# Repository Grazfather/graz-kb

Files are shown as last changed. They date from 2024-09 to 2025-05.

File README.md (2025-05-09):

# Graziano's keyboard

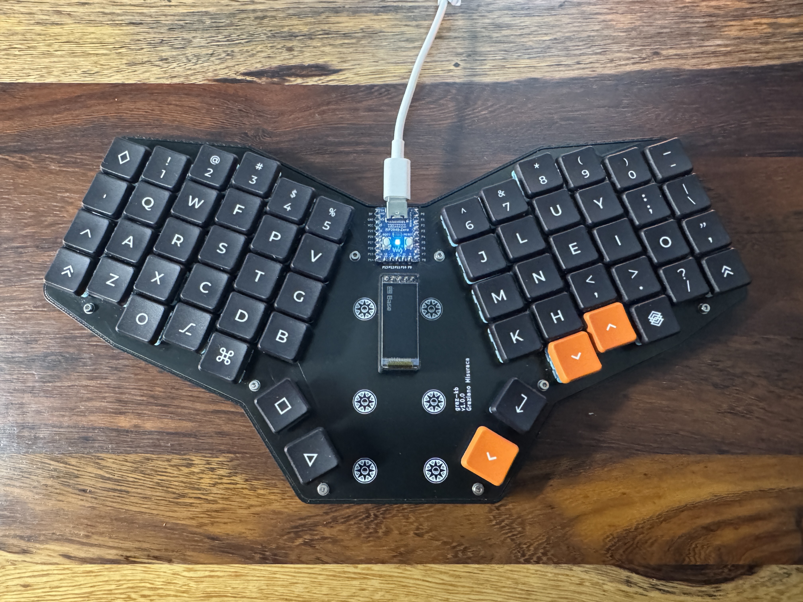
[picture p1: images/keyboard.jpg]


[ZMK configuration and keymap](https://github.com/Grazfather/zmk-config-grazkb)

* 58 key ergonomic wires keyboard.
* Full number row and alphabet (bare minimum for me)
* Low-profile choc switches
* 5 keys in the thumb cluster/row
* Designed using [Ergogen](https://github.com/ergogen/ergogen) and KiCad.
* ZMK Used for firmware.

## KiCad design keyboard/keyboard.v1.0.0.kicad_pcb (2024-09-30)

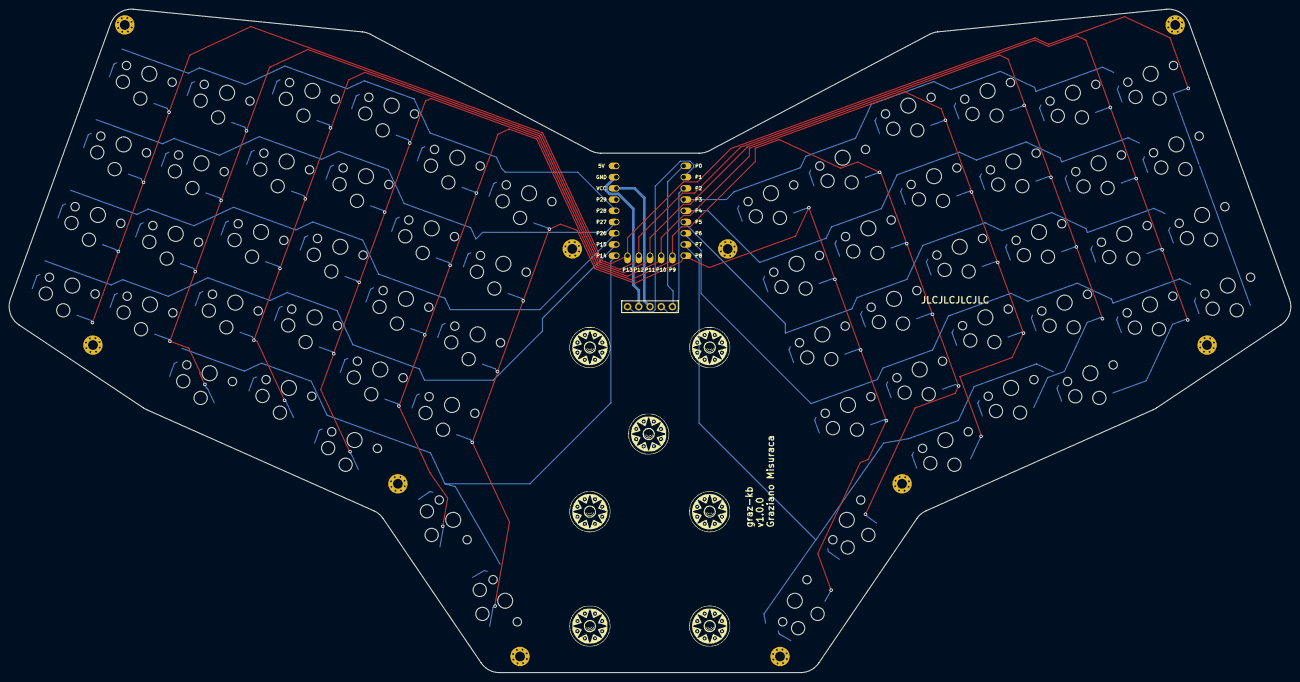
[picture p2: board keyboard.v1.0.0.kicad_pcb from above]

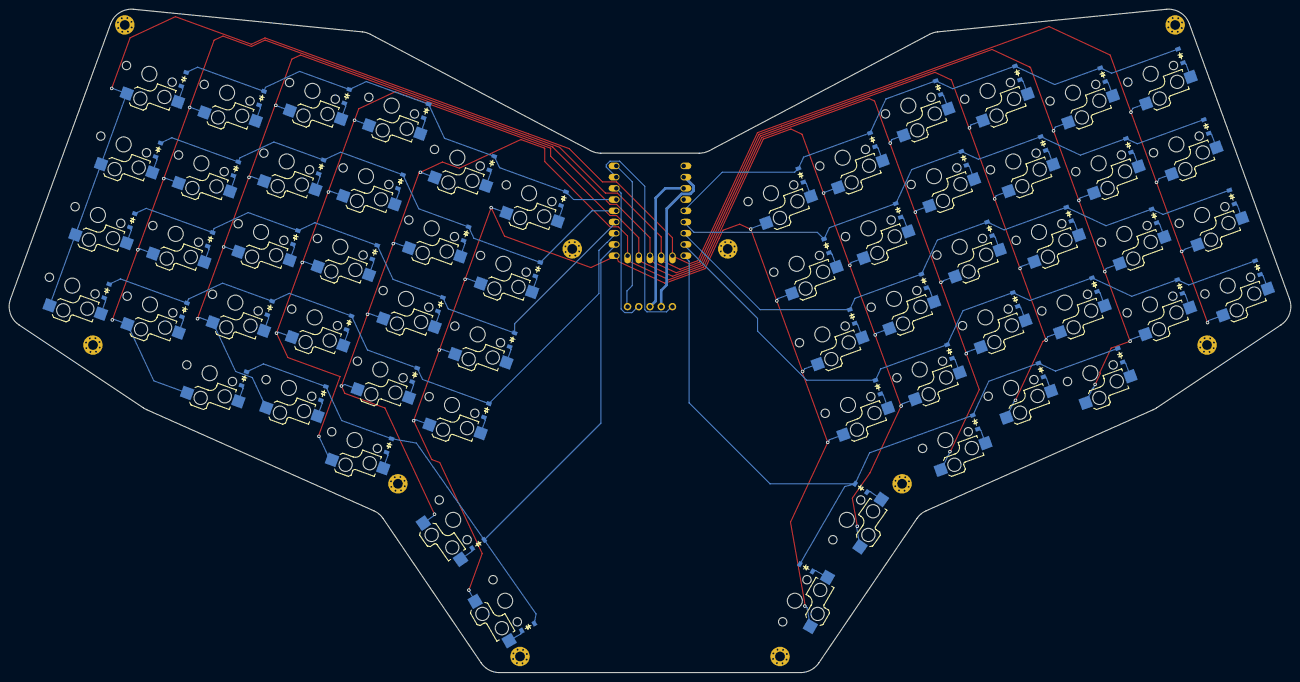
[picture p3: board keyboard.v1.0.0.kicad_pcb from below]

Board: 2 copper layers, 290.1 x 150.1 mm, 128 parts (116 on the bottom side), 79 nets.

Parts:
D1, D2, D3, D4, D5, D6, D7, D8, D9, D10, D11, D12, D13, D14, D15, D16, D17, D18, D19, D20, D21, D22, D23, D24, D25, D26, D27, D28, D29, D30, D31, D32, D33, D34, D35, D36, D37, D38, D39, D40, D41, D42, D43, D44, D45, D46, D47, D48, D49, D50, D51, D52, D53, D54, D55, D56, D57, D58: diode_tht_sod123
DISP1: nice_view
MCU1: Waveshare RP2040 Zero
S1, S2, S3, S4, S5, S6, S7, S8, S9, S10, S11, S12, S13, S14, S15, S16, S17, S18, S19, S20, S21, S22, S23, S24, S25, S26, S27, S28, S29, S30, S31, S32, S33, S34, S35, S36, S37, S38, S39, S40, S41, S42, S43, S44, S45, S46, S47, S48, S49, S50, S51, S52, S53, S54, S55, S56, S57, S58: switch_choc_v1_v2
_1, _2, _3, _3#2, _3#3, _4, _5, _6, _7, _8: MountingHole_2.2mm_M2_Pad_Via

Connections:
GND: DISP1.2, MCU1.22
OLED_MOSI: DISP1.5, MCU1.1
OLED_SCK: DISP1.4, MCU1.3
OLED_SS: DISP1.1, MCU1.2
VCC: DISP1.3, MCU1.21
col_index: MCU1.10, S20.1, S21.1, S22.1, S23.1, S28.1, S49.1, S50.1, S51.1, S52.1, S57.1
col_inner: MCU1.9, S24.1, S25.1, S26.1, S27.1, S29.1, S53.1, S54.1, S55.1, S56.1, S58.1
col_middle: MCU1.11, S15.1, S16.1, S17.1, S18.1, S19.1, S44.1, S45.1, S46.1, S47.1, S48.1
col_outer: MCU1.14, S1.1, S2.1, S3.1, S4.1, S30.1, S31.1, S32.1, S33.1
col_pinky: MCU1.13, S5.1, S6.1, S7.1, S8.1, S9.1, S34.1, S35.1, S36.1, S37.1, S38.1
col_ring: MCU1.12, S10.1, S11.1, S12.1, S13.1, S14.1, S39.1, S40.1, S41.1, S42.1, S43.1
far_thumb: D29.2, S29.2
home_thumb: D28.2, S28.2
index_bottom: D20.2, S20.2
index_home: D21.2, S21.2
index_mod: D19.2, S19.2
index_num: D23.2, S23.2
index_top: D22.2, S22.2
inner_bottom: D24.2, S24.2
inner_home: D25.2, S25.2
inner_num: D27.2, S27.2
inner_top: D26.2, S26.2
middle_bottom: D15.2, S15.2
middle_home: D16.2, S16.2
middle_mod: D14.2, S14.2
middle_num: D18.2, S18.2
middle_top: D17.2, S17.2
mirror_far_thumb: D58.2, S58.2
mirror_home_thumb: D57.2, S57.2
mirror_index_bottom: D49.2, S49.2
mirror_index_home: D50.2, S50.2
mirror_index_mod: D48.2, S48.2
mirror_index_num: D52.2, S52.2
mirror_index_top: D51.2, S51.2
mirror_inner_bottom: D53.2, S53.2
mirror_inner_home: D54.2, S54.2
mirror_inner_num: D56.2, S56.2
mirror_inner_top: D55.2, S55.2
mirror_middle_bottom: D44.2, S44.2
mirror_middle_home: D45.2, S45.2
mirror_middle_mod: D43.2, S43.2
mirror_middle_num: D47.2, S47.2
mirror_middle_top: D46.2, S46.2
mirror_outer_bottom: D30.2, S30.2
mirror_outer_home: D31.2, S31.2
mirror_outer_num: D33.2, S33.2
mirror_outer_top: D32.2, S32.2
mirror_pinky_bottom: D34.2, S34.2
mirror_pinky_home: D35.2, S35.2
mirror_pinky_num: D37.2, S37.2
mirror_pinky_top: D36.2, S36.2
mirror_ring_bottom: D39.2, S39.2
mirror_ring_home: D40.2, S40.2
mirror_ring_mod: D38.2, S38.2
mirror_ring_num: D42.2, S42.2
mirror_ring_top: D41.2, S41.2
mirror_row_bottom: D30.1, D34.1, D39.1, D44.1, D49.1, D53.1, MCU1.7
mirror_row_home: D31.1, D35.1, D40.1, D45.1, D50.1, D54.1, MCU1.6
mirror_row_mod: D38.1, D43.1, D48.1, D57.1, D58.1, MCU1.8
mirror_row_num: D33.1, D37.1, D42.1, D47.1, D52.1, D56.1, MCU1.4
mirror_row_top: D32.1, D36.1, D41.1, D46.1, D51.1, D55.1, MCU1.5
outer_bottom: D1.2, S1.2
outer_home: D2.2, S2.2
outer_num: D4.2, S4.2
outer_top: D3.2, S3.2
pinky_bottom: D5.2, S5.2
pinky_home: D6.2, S6.2
pinky_num: D8.2, S8.2
pinky_top: D7.2, S7.2
ring_bottom: D10.2, S10.2
ring_home: D11.2, S11.2
ring_mod: D9.2, S9.2
ring_num: D13.2, S13.2
ring_top: D12.2, S12.2
row_bottom: D1.1, D5.1, D10.1, D15.1, D20.1, D24.1, MCU1.16
row_home: D2.1, D6.1, D11.1, D16.1, D21.1, D25.1, MCU1.17
row_mod: D9.1, D14.1, D19.1, D28.1, D29.1, MCU1.15
row_num: D4.1, D8.1, D13.1, D18.1, D23.1, D27.1, MCU1.19
row_top: D3.1, D7.1, D12.1, D17.1, D22.1, D26.1, MCU1.18

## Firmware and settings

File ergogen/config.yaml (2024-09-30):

# https://ergogen.cache.works/
meta:
  version: 1.1.0
units:
  # Choc spacing
  kx: cx
  ky: cy
  # Padding Variables
  px: kx + 4
  py: ky + 4
  led_pos_x: 0 # Led X position relative to the switch center
  led_pos_y: 4.7 # Led Y position relative to the switch center
  kcow: 13.8 # key cutout hole width (cherry, choc v2: 14, choc v1: 13.8)
  kcoh: 13.8 # key cutout hole height (cherry, choc v2: 14, choc v1: 13.8)
  keycw: 17.5 # keycap width (cherry: 18, choc: 17.5)
  keych: 16.5 # keycap height (cherry: 18, choc: 16.5)
  vertical_diode_shift: 1.5 # How much to shift to avoid overlap
  horizontal_diode_shift: -0.5 kcow - 0.85
  diode_rotation: -180
  switch_rotation: 180 # Hotswap south, led north
  screw_radius: 1.1 # M2 screws
  # For preview only. We show slightly smaller to ID overlaps
  $default_width: cx-1
  $default_height: cy-1
points:
  rotate: -20
  key:
    padding: ky
    spread: kx
    tags:
      1u: true
  zones:
    matrix:
      key.tags:
        - key
      # Fix placement on KiCAD sheet
      anchor:
        shift: [100, -100]
      columns:
        outer:
          rows:
            mod.skip: true
            bottom.key:
              led_prev: LED_4
              led_next: LED_5
            home.key:
              led_prev: LED_3
              led_next: LED_4
            top.key:
              led_prev: LED_2
              led_next: LED_3
            num.key:
              led_prev: LED_1
              led_next: LED_2
          key:
            column_net: col_outer
        pinky:
          rows:
            mod.skip: true
            bottom.key:
              led_prev: LED_6
              led_next: LED_7
            home.key:
              led_prev: LED_7
              led_next: LED_8
            top.key:
              led_prev: LED_8
              led_next: LED_9
            num.key:
              led_prev: LED_9
              led_next: LED_10
          key:
            stagger: 2
            column_net: col_pinky
        ring:
          key:
            stagger: 7
            column_net: col_ring
          rows:
            mod.column_net: col_pinky
            mod.key:
              led_prev: LED_5
              led_next: LED_6
            bottom.key:
              led_prev: LED_13
              led_next: LED_14
            home.key:
              led_prev: LED_12
              led_next: LED_13
            top.key:
              led_prev: LED_11
              led_next: LED_12
            num.key:
              led_prev: LED_10
              led_next: LED_11
        middle:
          key:
            stagger: 3
            column_net: col_middle
          rows:
            mod.column_net: col_ring
            mod.key:
              led_prev: LED_14
              led_next: LED_15
            bottom.key:
              led_prev: LED_16
              led_next: LED_17
            home.key:
              led_prev: LED_17
              led_next: LED_18
            top.key:
              led_prev: LED_18
              led_next: LED_19
            num.key:
              led_prev: LED_19
              led_next: LED_20
        index:
          key:
            stagger: -6
            column_net: col_index
          rows:
            mod.column_net: col_middle
            mod.key:
              led_prev: LED_15
              led_next: LED_16
            bottom.key:
              led_prev: LED_23
              led_next: LED_24
            home.key:
              led_prev: LED_22
              led_next: LED_23
            top.key:
              led_prev: LED_21
              led_next: LED_22
            num.key:
              led_prev: LED_20
              led_next: LED_21
        inner:
          rows:
            mod.skip: true
            bottom.key:
              led_prev: LED_26
              led_next: LED_27
            bottom.mirror.key:
              led_prev: LED_33
              led_next: LED_34
            home.key:
              led_prev: LED_27
              led_next: LED_28
            home.mirror.key:
              led_prev: LED_32
              led_next: LED_33
            top.key:
              led_prev: LED_28
              led_next: LED_29
            top.mirror.key:
              led_prev: LED_31
              led_next: LED_32
            num.key:
              led_prev: LED_29
              led_next: LED_30
            num.mirror.key:
              led_prev: LED_30
              led_next: LED_31
          key:
            stagger: -2
            column_net: col_inner
      rows:
        mod:
          row_net: row_mod
          mirror.row_net: mirror_row_mod
        bottom:
          row_net: row_bottom
          mirror.row_net: mirror_row_bottom
        home:
          row_net: row_home
          mirror.row_net: mirror_row_home
        top:
          row_net: row_top
          mirror.row_net: mirror_row_top
        num:
          row_net: row_num
          mirror.row_net: mirror_row_num
    thumbfan:
      key.tags:
        - key
      anchor:
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

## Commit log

2024-03-03 Add PCB tips resource
2024-03-03 Adjust thumb fan position
2024-03-07 Add stuff for pcb
2024-03-13 Create extra keyboard with less mods, create PCBs
2024-03-13 Add mounting holes
2024-03-20 Fix index finger stagger
    [config.yaml]
2024-03-20 Switch to 10 row 6 column and assign pins + oled
2024-03-25 Add ceoloide's ergogen-footprints as a submodule
2024-03-26 Fix row and column nets on thumb cluster
    [config.yaml]
2024-09-30 Adjust mounting holes so they don't interfere with any pads or switches
    [config.yaml]
2024-09-30 Resist mirroring for diodes
2024-09-30 update ceoloide's footprints
2024-09-30 Add models to footprints
2024-09-30 Move mounting holes so they aren't under any keys
2024-09-30 Add more mounting holes and move some
2024-09-30 Fix positioning of OLED display
    [config.yaml]
2024-09-30 Move mounting hole defs into points¬
2024-09-30 Update ceoloide footprints
2024-09-30 Add my waveshare zero footprint
2024-09-30 Add v1.0.0 pcb file
    [keyboard.v1.0.0.kicad_pcb]
2024-09-30 Add v1.0.0 gerber files
2024-09-30 BUG FIX: Put OLED MOSI on actual MOSI-cap pin
    [config.yaml]
2024-09-30 Include silkscreen for nice_view
2024-09-30 wip: per key leds
